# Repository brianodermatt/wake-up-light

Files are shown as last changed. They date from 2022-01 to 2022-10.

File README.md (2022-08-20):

# wake-up-light

A wake-up light simulating the sunrise with RGB LEDs based on a Raspberry Pi.

## Hardware

### List of components

- [List of used hardware](theory/MAyyTERIAL.md)

### Schematics

Schematics are drawn on [KiCad](https://www.kicad.org/download/ubuntu/) which can be installed using:

```bash
sudo add-apt-repository --yes ppa:kicad/kicad-6.0-releases
sudo apt update
sudo apt install --install-recommends kicad -y
```

### Useful documents

- [Raspberry Pi R1/R2 GPIO pinout](datasheets/raspberrypi_R1_R2_gpio_pinout.png)
- [Raspberry Pi Zero 2W GPIO pinout](datasheets/RaspberryPi_zero_2_w_gpio_pinout.webp)
- [Resistor color code](datasheets/resistor_color_code.png)

### LED driver

#### Calculations

Single BJT NPN with grounded emitter, base connected to GPIO via 10k resistance, collector connected to 5V (`V_DD`) via LED and resistor `R_L`.
From `I_LED = (V_DD - V_f - V_CE,sat) / R_L` follows `R_L = (V_DD - V_f - V_CE,sat) / I_LED`.

The base resistor `R_B` is scaled to protect the GPIO port and limit the max current: `U_GPIO = R_B * I_B + V_BE`, from which follows `I_B = (U_GPIO - V_BE) / R_B < I_GPIO = 16mA`. Thus, `R_B > (U_GPIO - V_BE) / I_GPIO > U_GPIO / I_GPIO = 3.3V / 16mA = 206 Ohm`. `R_B = 220 Ohm` is selected.

#### Test setup ([schematic files](schematics/test-setup))

- LEDs: Cheap LEDs to be driven with `i = 20mA`
  - Red: `V_f = 1.8V`
  - Green, Blue: `V_f = 3.2V`
- Transistor: BJT NPN S9018 ([datasheet](datasheets/BJT_NPN_S9018.pdf))
  - `V_CE,sat = 0.1V @20mA`
- Red: `R_L > 155 Ohm`; Green, Blue: `R_L > 85 Ohm`.

#### Real setup ([schematic files](schematics/power-setup))

- LEDs: [Adafruit 3W-9W RGB LED2524](datasheets/LED_RGB_Adafruit_2524.pdf) to be driven with `[350, 700]mA`. Here: `i=500mA`.
  - Red: `V_f = 3.2V`
  - Green, Blue: `V_f = 4.1V`
- Transistor: BJT NPN S9013 ([datasheet](datasheets/BJT_NPM_S9013.pdf))
  - `V_CE,sat = 0.6V @500mA`
- Red: `R_L > 2.4 Ohm`; Green, Blue: `R_L > 0.6 Ohm`.
- Red: `2.4 Ohm`; Green, Blue: `2.4 || 2.4 || 2.4 || 2.4 = 0.6 Ohm`;

## User's guide

1. [Setup Raspberry Pi](theory/SETUP-RASPBERRY-PI.md)

## Troubleshooting

[Troubleshooting](theory/TROUBLESHOOTING.md)

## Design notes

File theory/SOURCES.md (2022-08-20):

# Sources

## Main sources of information

- [Similar Project of a wake-up light with a Raspberry Pi](https://rdrn.me/wake-up-light)
- [LED Driver with 3 BJT](https://maker.pro/custom/tutorial/creating-constant-current-supply-with-led-drivers)

## Electrical diagrams

[app.diagrams.net](https://app.diagrams.net/)

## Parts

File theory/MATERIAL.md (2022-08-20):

# Material & Tools

## Material

- [x] Raspberry Pi with WiFi: [CHF 14.86](https://www.digikey.ch/product-detail/de/raspberry-pi/SC0510/2648-SC0510-ND/15298147)
- [x] Raspberry Pi Power supply: [CHF 7.93](https://www.digikey.ch/product-detail/de/raspberry-pi/RPI-USB-C-POWER-SUPPLY-BLACK-EU/1690-RPIUSB-CPOWERSUPPLYBLACKEU-ND/10258762)
- [x] Adapter USB-C -> micro-USB: [CHF 0.79](https://www.aliexpress.com/item/1005001355311385.html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)
- [x] SD-card for Raspberry Pi: [CHF 9.09](https://www.digikey.ch/product-detail/de/delkin-devices-inc/USDCOEM-16GB/3247-USDCOEM-16GB-ND/13882332)
- [x] RGB LED: [CHF 3.91](https://www.digikey.ch/en/products/detail/adafruit-industries-llc/2524/9770537)
- [x] BJT NPN: S9013 (available in-house)
- [x] Power Resistors [>10pcs: CHF 0.06](https://www.digikey.ch/de/products/detail/stackpole-electronics-inc/CF12JT2R40/1741072)
- [x] Heat sink for LED [CHF 0.93](https://www.digikey.ch/en/products/detail/watterott-electronic-gmbh/20188/10071165)
- [x] Wires
  - Fabrication Wires 2m, <0.8A
    - [x] Green [CHF 0.74](https://www.digikey.ch/de/products/detail/adafruit-industries-llc/2005/6827152)
    - [x] Blue [CHF 0.74](https://www.digikey.ch/de/products/detail/adafruit-industries-llc/2002/6827149)
    - [x] Black [CHF 0.74](https://www.digikey.ch/de/products/detail/adafruit-industries-llc/2003/6827150)
    - [x] Yellow [CHF 0.74](https://www.digikey.ch/de/products/detail/adafruit-industries-llc/2004/6827151)
    - [x] Red [CHF 0.74](https://www.digikey.ch/de/products/detail/adafruit-industries-llc/2001/6827148)
    - [x] White [CHF 0.74](https://www.digikey.ch/de/products/detail/adafruit-industries-llc/2006/6827153)
- [x] Prototype Board: Adafruit 4784 [CHF 2.48](https://www.digikey.ch/product-detail/en/adafruit-industries-llc/4784/1528-4784-ND/13617526)

For possible additional features (not used in V1):

- [x] Button for display activation [CHF 0.10](https://www.digikey.ch/de/products/detail/apem-inc/MJTP1230/1798037)
- [x] I2C Display [CHF 5.45](https://www.digikey.ch/product-detail/de/seeed-technology-co-ltd/104020208/1597-104020208-ND/10667534)
- [ ] Speaker (USB powered) [CHF 15.90](https://www.digitec.ch/de/s1/product/speedlink-twoxo-pc-lautsprecher-5920467)

## Tools

- [x] Jumper Wires
  - [x] 10cm M2M [CHF 2.48](https://www.digikey.ch/en/products/detail/sparkfun-electronics/PRT-14284/7324438)
  - [x] 7.6cm F2F [CHF1.93](https://www.digikey.ch/en/products/detail/adafruit-industries-llc/1951/6827085)
  - [x] 15cm M2F [CHF 1.93](https://www.digikey.ch/en/products/detail/adafruit-industries-llc/1954/6827087)
- [x] Soldering iron [CHF 24.10](https://www.digitec.ch/de/s1/product/velleman-regelbare-loetstation-loetgeraet-5778964)
- [x] Tin [CHF 19.50](https://www.digikey.ch/product-detail/en/chip-quik-inc/RASWLF-031-4OZ/RASWLF-0314OZ-ND/9682001)
- [x] Desoldering braid [CHF 2.12](https://www.digikey.ch/product-detail/en/aven-tools/17540/243-1185-ND/1992579)
- [x] Breadboard [CHF 19.76](https://www.digikey.ch/en/products/detail/adafruit-industries-llc/443/6623851)
- [x] Wire stripper [CHF 11.84](https://www.digikey.ch/de/products/detail/adafruit-industries-llc/4747/13250941)

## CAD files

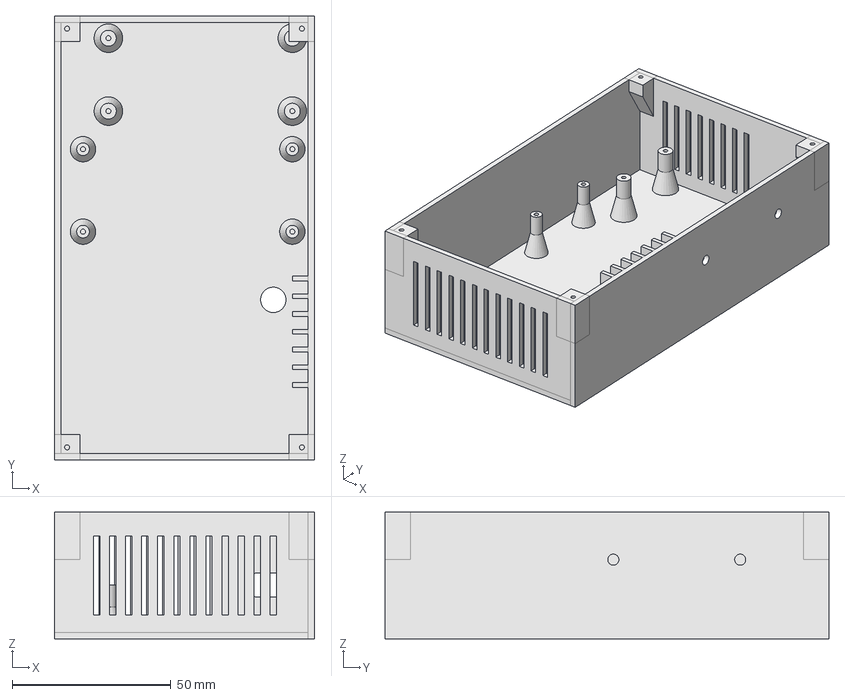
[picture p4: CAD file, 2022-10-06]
cad/case.FCStd
82.0 x 140.0 x 40.0 mm

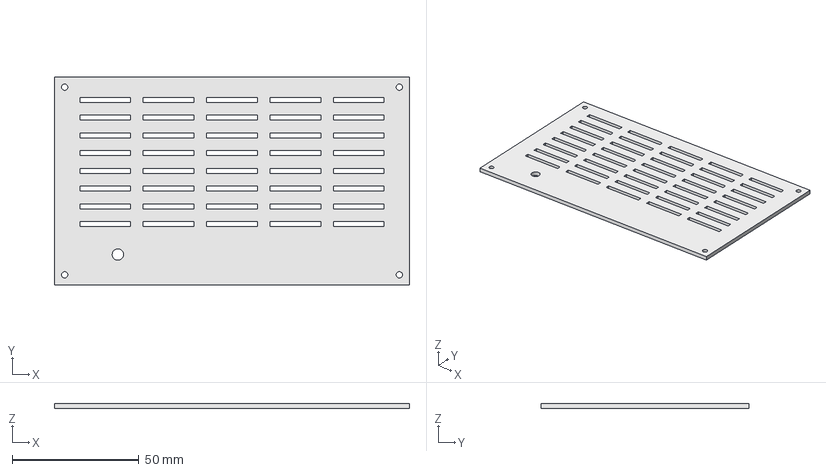
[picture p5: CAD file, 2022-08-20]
cad/cover.FCStd
140.0 x 82.0 x 2.00 mm

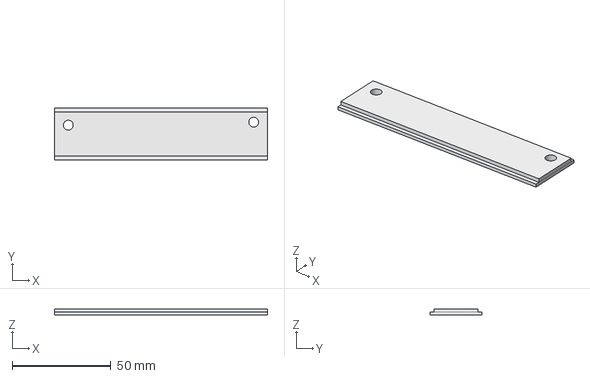
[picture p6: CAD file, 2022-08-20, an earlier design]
cad/ARCHIVE/cover.FCStd
108.0 x 26.5 x 3.25 mm

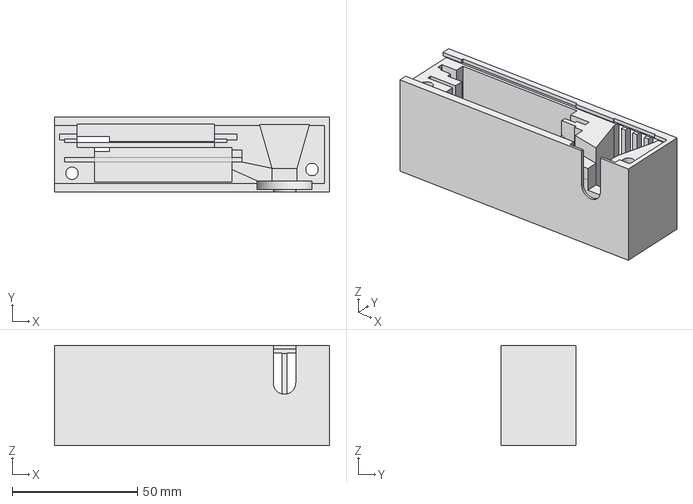
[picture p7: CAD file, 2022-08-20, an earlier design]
cad/ARCHIVE/case.FCStd
110.0 x 30.0 x 40.0 mm

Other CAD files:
cad/case.stl
cad/cover.stl

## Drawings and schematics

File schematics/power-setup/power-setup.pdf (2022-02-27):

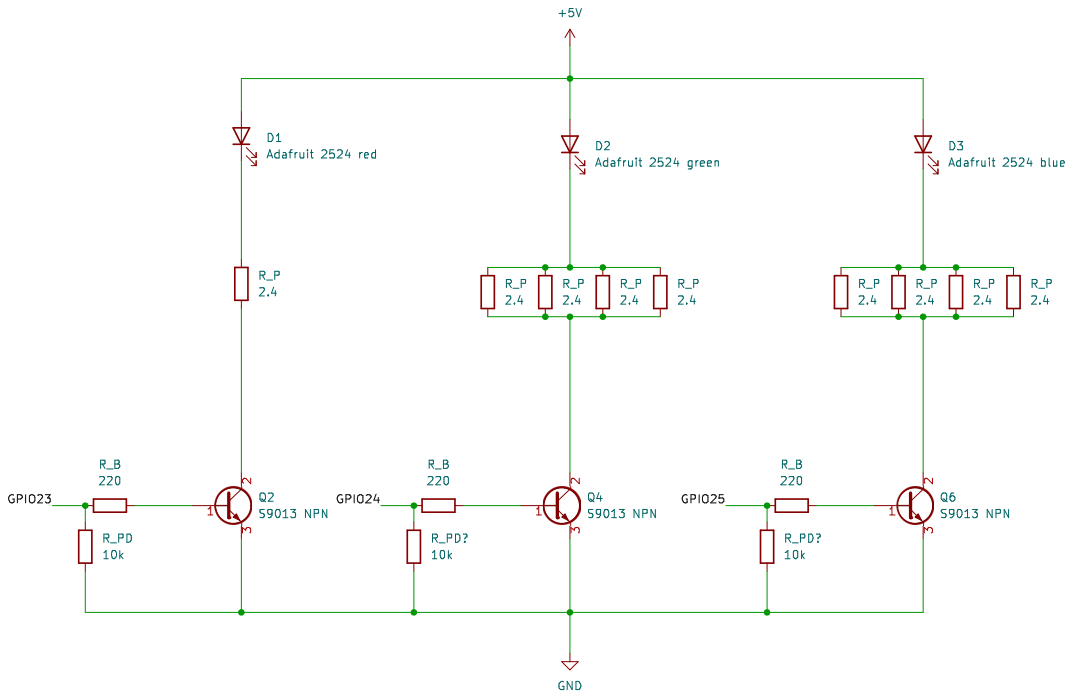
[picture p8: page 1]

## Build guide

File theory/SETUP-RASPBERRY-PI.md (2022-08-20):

# Raspberry Pi Setup

## Conventions

Here, items prefixed with `$` can be replaced with the respective tokens:

```
$USER: brian
```

## Install Raspberri Pi OS

Use Raspberry Pi Imager to install Raspbian (used: Raspberry Pi Imager v1.6.2).

- Select OS: Raspberry Pi OS (other) -> Raspberry Pi OS Lite (32-bit).
- Press `CTRL+SHIFT+x` to open advanced options.
- Set hostname: `wakeup`.local
- Enable SSH, set a password and write it down.
- Configure WiFi with SSID, password, country.

## Startup

- Insert SD card into Raspberry Pi, connect Ethernet, connect power.
- Wait for a few minutes, especially during first startup.

## SSH Connection

- Use the previously configured hostname: `wakeup.local`.
- Instead, you can also use the IP. You can find the IP address of the Raspberry Pi using your router's web interface for example. In my case it is `192.168.0.25`.
- Connect to the Raspbery Pi using SSH
  - On Ubuntu: `ssh pi@wakeup.local` (or `ssh pi@192.168.0.25`).
  - On Windows you may need to use Putty.

## System Configuration

- Connected to the Raspberry via ssh, run `sudo raspi-config` to open the configuration tool.
- Set the correct locale: `5 Localisation Options` > `L1 Locale` (in my case `de_CH.UTF-8` with the default system locale `en_GB.UTF-8`).
- Set the correct timezone: `5 Localisation Options` > `L2 Timezone` (in my case `Europe` > `Zurich`).
- Expand filesystem: `6 Advanced Options` > `A1 Expand Filesystem`
- Reduce memory for GPU (as we are running headless): `4 Performance` > `P2 GPU Memory`. Set minimum (in my case `16 MB`).
- Quit the config tool. When asked to reboot, allow.

## Installation

- Install git: `sudo apt install git -y`
- Clone this repo on the Raspberry: `git clone https://github.com/brianodermatt/wake-up-light -b main`
- Install the needed software. This upgrades the system, installs python, some python packages, as well as [pigpio](https://github.com/joan2937/pigpio) for LED PWM. It will furthermore set the needed permissions and register the server for starting upon boot. The execution of this script may take several minutes.

  ```bash
  chmod +x wake-up-light/src/install/install-deps.sh
  ./wake-up-light/src/install/install-deps.sh
  ```

- Reboot: `sudo reboot`

## Disable system LEDs
<!--(TODO)-->
DISCLAIMER: not yet tested

Add the following lines to `/boot/config.txt`:

```txt
# Disable the ACT LED on the Pi Zero.
dtparam=act_led_trigger=none
dtparam=act_led_activelow=on
```

## Manually test GPIO / LED

`raspi-gpio get` prints the state of all GPIO pins
`raspi-gpio get X` prints the state of GPIO pin X
`raspi-gpio set X op` sets GPIO pin X as an output
`raspi-gpio set X dh` sets GPIO pin X to drive high
`raspi-gpio set X dl` sets GPIO pin X to drive low

Make sure to reboot afterwards to reset the configuration

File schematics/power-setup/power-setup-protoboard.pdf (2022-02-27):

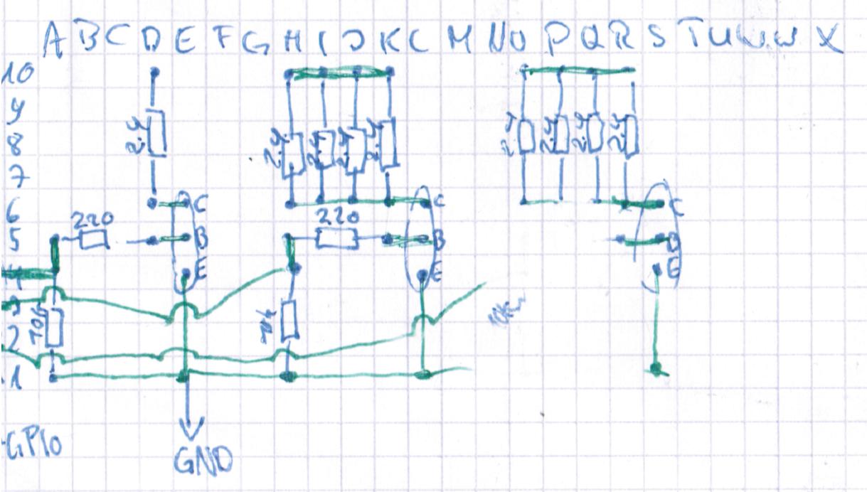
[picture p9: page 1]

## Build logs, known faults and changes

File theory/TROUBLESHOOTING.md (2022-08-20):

# Troubleshooting

## OS installation on SD card

- Try a different cardreader / adapter
- `lsblk` displays all the available devices with their size. The SD could be something like `sdf` with partitions `sdf1` and `sdf2`.
- `gparted` shows partitions on device
- mount one of the partitions to a folder created by `sudo mkdir /media/$USER/SD`: `sudo mount -t vfat /dev/sdf1 /media/$USER/SD`

## SSH connection

- Remove an old SSH key if you experimented with another Raspberry Pi before and now get an error while connecting to the new one: `ssh-keygen -R wakeup.local`

## Cron jobs

- list scheduled cron jobs: `sudo crontab -l`
- access logs of crontab jobs (crontab needs a Mail Transfer Agent which is not installed on Ubuntu by default; select `Local only` / `wakeup` during the installation process of postfix):

  ```bash
  sudo apt-get install postfix -y
  sudo tail -f /var/mail/root
  ```

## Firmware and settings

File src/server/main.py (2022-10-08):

#!/usr/bin/env python3

import os
import json
from flask import Flask, render_template, request, jsonify
from crontab import CronTab

STORE_PATH = 'store.json'
LIGHTS_PATH = os.getcwd() + '/lights.py'
DAYS = ["monday", "tuesday", "wednesday",
        "thursday", "friday", "saturday", "sunday"]
CRON_COMMENT = 'wakeup-light'

app = Flask(__name__, template_folder='../web/templates',
            static_url_path="", static_folder="../web/static")


# Display the web page
@app.route('/')
def index():
    with open(STORE_PATH, 'r') as f:
        store = json.load(f)
    print(store)
    return render_template("index.html", store=store, DAYS=DAYS)


# API: Update the timing
@app.route("/api/update", methods=["POST"])
def update():
    print("Updating")

    data = request.get_json()
    print(data)

    # Save to store
    with open(STORE_PATH, "w") as f:
        json.dump(data, fp=f)

    # Create cron jobs
    cron = CronTab(user="root")
    cron.remove_all(comment="wakeup-light")

    for key, value in data.items():
        # data: { [day]: dayData, hold: number }
        print(f'{key}:')
        print(value)
        if key == 'hold':
            continue
        if value['active']:
            hour, minute = value['time'].split(":")
            day = DAYS.index(key) + 1
            job = cron.new(
                command=f"{ LIGHTS_PATH } sunrise { value['duration'] } { data['hold'] }",
                comment="wakeup-light",
            )
            job.minute.on(minute)
            job.hour.on(hour)
            job.dow.on(day)

    cron.write()

    return jsonify("Updated")


if __name__ == "__main__":
    app.run(debug=True, host="0.0.0.0", port=80)

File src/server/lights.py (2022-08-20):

#!/usr/bin/env python3

# Imports
import time
import sys
import pigpio
import numpy as np
from scipy import interpolate


# Constants
# pigpio has 255 steps of brightness: pi.set_PWM_dutycycle(pin, 255) corresponds to full brightness
RANGE = 255
STEPS = 100  # The number of steps to make during sunrise
PINS = {  # The GPIO number of the pin for each color
    "red": 23,
    "green": 24,
    "blue": 25
}
START = {  # Starting point (time) of each color in [0, 1]
    "red": 0,
    "green": 1/3,
    "blue": 2/3,
}
END = {  # Ending point (time) of each color in [0, 1]
    "red": 1,
    "green": 1,
    "blue": 1,
}
# Maximum intensity of the lights (lower if stuff gets too hot)
MAX_INTENSITY = 0.6
# The growing function for the light [0,1] |-> [0,1]
GROWTH_FUNC = interpolate.interp1d(
    [0.0, 0.2, 0.4, 0.6, 0.8, 1.0],  # x of the interpolation
    [0.0, 0.1, 0.3, 0.6, 0.8, 1.0],  # y of the interpolation
    fill_value="extrapolate"
)


# Initialization
pi = pigpio.pi()
for pin in PINS.values():
    pi.set_PWM_frequency(pin, 400)


# Sunrise: Duration is specified in minutes
def sunrise(duration_min, hold_min):
    interval_length_s = 60 * duration_min / STEPS

    for step in range(STEPS + 1):
        progress = step / STEPS  # progress in [0, 1]

        print(f'{progress*100:3.0f}%: ', end='')
        for color in ["red", "green", "blue"]:
            color_progress = bound(0, 1, scaleFctToInt(
                START[color], END[color], GROWTH_FUNC, progress))
            cmd = RANGE * color_progress * MAX_INTENSITY
            pi.set_PWM_dutycycle(PINS[color], cmd)
            print(
                f'{color[0].capitalize()}:{color_progress * 100:3.0f}% ({cmd:3.0f}) ', end='')
        print('')

        # Sleep to reach the overall duration
        time.sleep(interval_length_s)

    # Remain at full light
    print(f'Remain at full light for {hold_min} min')
    time.sleep(hold_min * 60)


# Bound the value between low and high
def bound(low, high, value):
    return max(low, min(high, value))


# Scale function to interval
def scaleFctToInt(start, end, func, value):
    return 1 * (func((value - start) / (end - start)))


# Cleanup (reset all channels)
def cleanup():
    for pin in PINS.values():
        pi.set_PWM_dutycycle(pin, 0)
    pi.stop()


# Call desired function if called via terminal
if __name__ == "__main__":
    func = sys.argv[1]
    duration = float(sys.argv[2])
    hold_min = float(sys.argv[3])
    try:
        if func == "sunrise":
            sunrise(duration, hold_min)
    except KeyboardInterrupt:
        pass
    finally:
        cleanup()

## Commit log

2021-11-19 Update material list
2021-11-28 Update materials list
2021-11-28 Add LED driver circuit
2022-01-28 Improve docs
    [test-setup.kicad_pcb, test-setup.kicad_sch]
2022-02-11 Add Raspberry Pi Zero 2W datasheets
2022-02-27 Setup is running!
    [power-setup.kicad_sch]
